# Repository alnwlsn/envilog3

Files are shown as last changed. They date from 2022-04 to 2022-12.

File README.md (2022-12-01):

# envilog3
2022 version of my enviromental logger board - original version documented on [Hackaday.io](https://hackaday.io/project/160740-low-power-environment-monitor-logger) or [my website](https://alnwlsn.com/projectrepository/index.php/Electronic_Time_Capsule).

This is a little board that I packed with batteries, some sensors, a Flash chip, and an RTC. When the RTC wakes up the board on some interval (programmable; minutes to an hour), it reads the sensors and stores the data in the Flash chip. The rest of the time, the board is in a low power sleep state, drawing <10uA. With 4xAA cells of power, the whole thing should run for several years.

I added a bunch of sensor footprints to this version because I had space and wasn't sure which ones I'd be able to get in the 2022 chip shortage. But, the firmware provided is for this configuration:
* BME280 (pressure, temperature, humidity)
* SHT31-DIS (temperature, humidity)
* BH1730FVC (light sensor; visible & IR)
* DS3232M (Real-time clock chip, also contains temperature sensor)
* Battery voltage (using Atmega ADC & voltage divider)
* 16MB of Flash; enough for 512K samples.
  * This is about 1 year of data at a 1 minute interval. Scale as needed - I'm going for 6 minute interval --> 6 years.

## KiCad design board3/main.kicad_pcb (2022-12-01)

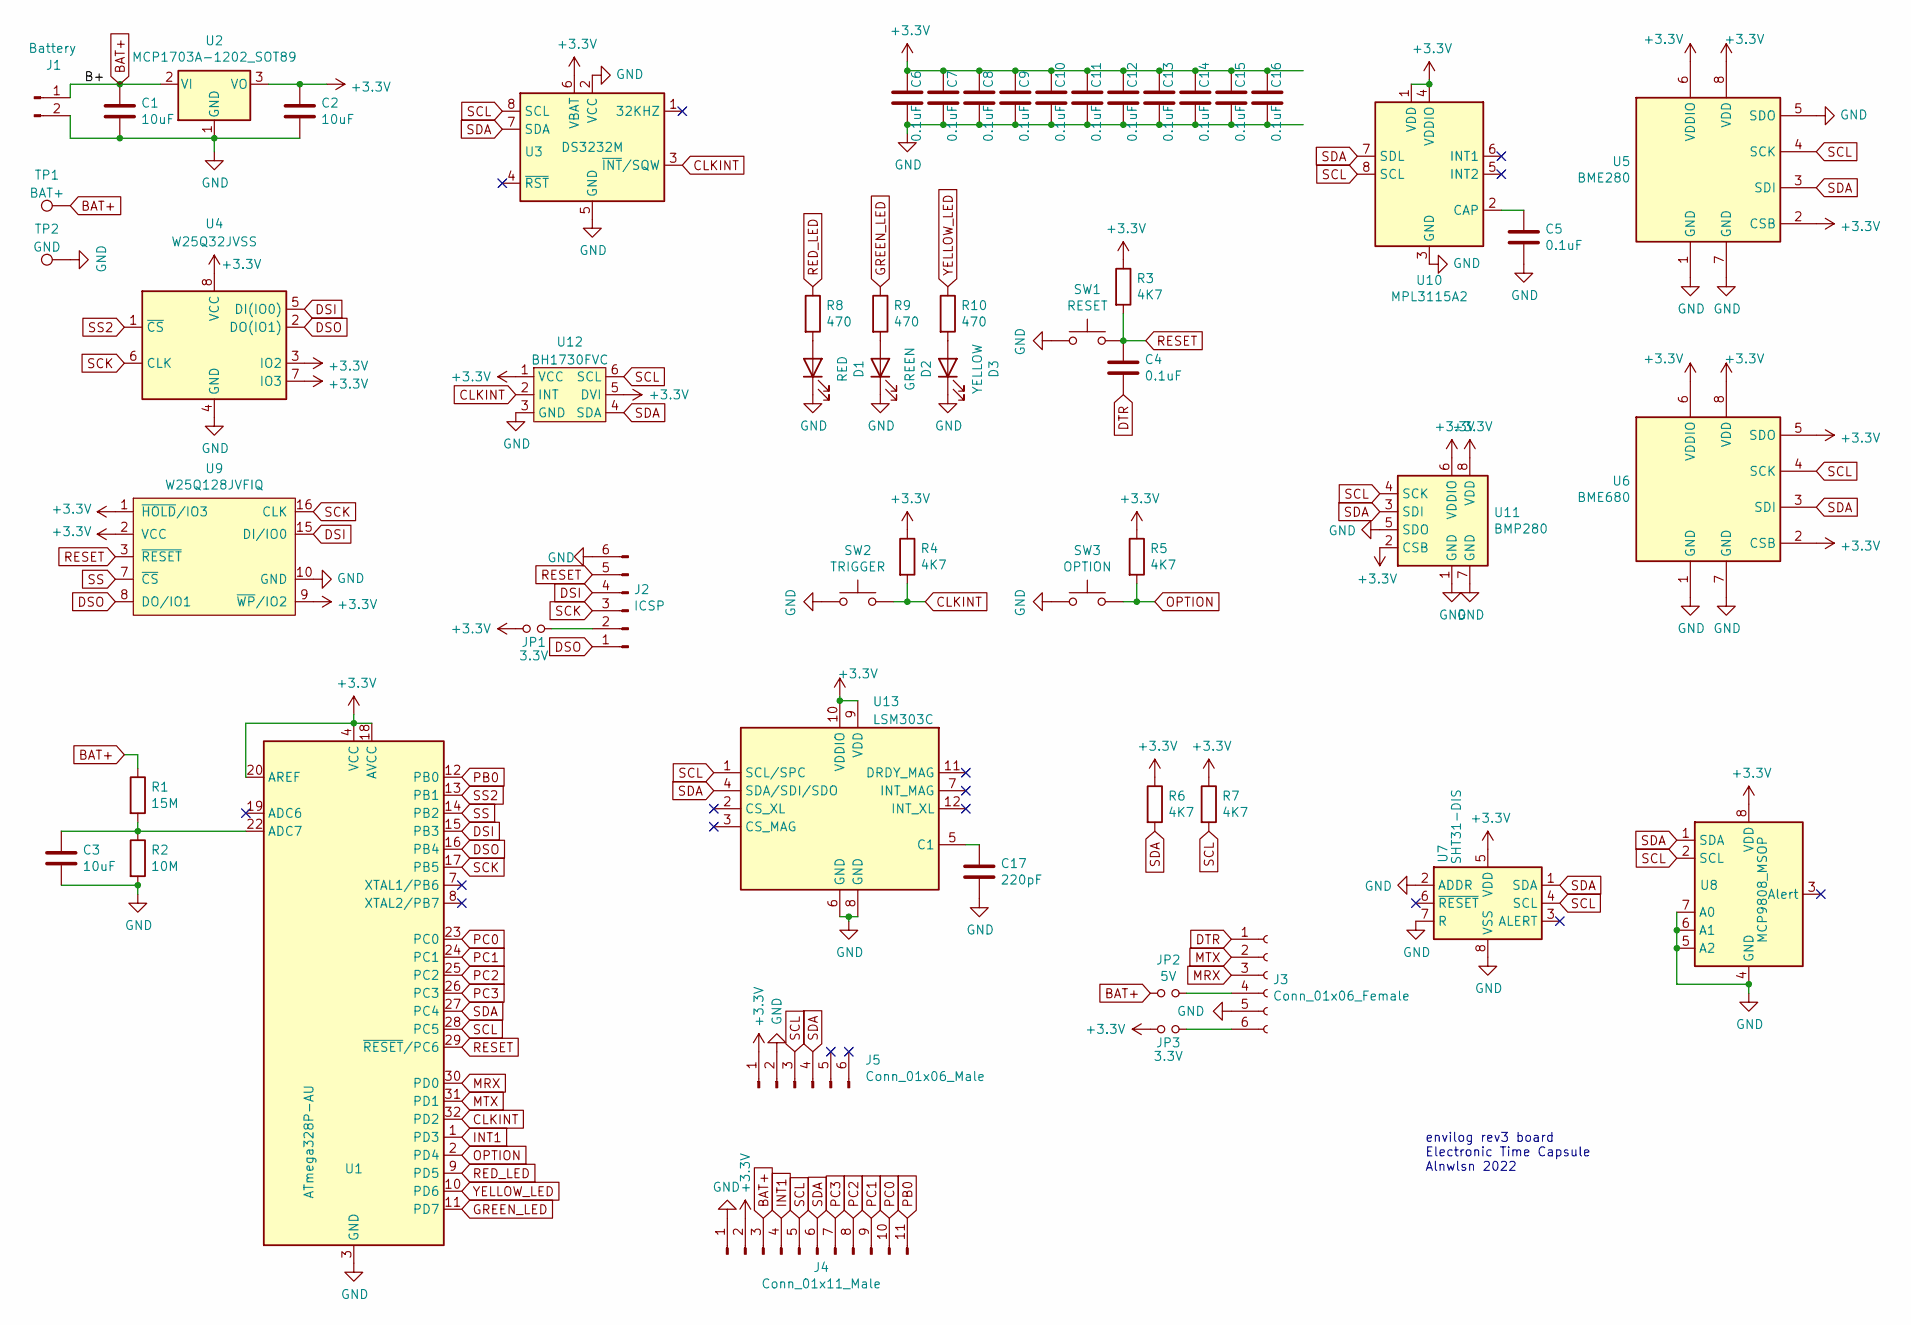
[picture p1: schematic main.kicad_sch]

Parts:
C1, C2, C3: 10uF; C_0805_2012Metric
C4, C5, C6, C7, C8, C9, C10, C11, C12, C13, C14, C15, C16: 0.1uF; C_0805_2012Metric
C17: 220pF; C_0805_2012Metric
D1: RED; LED_0805_2012Metric
D2: GREEN; LED_0805_2012Metric
D3: YELLOW; LED_0805_2012Metric
J1: Battery; PinHeader_1x02_P2.54mm_Vertical
J2: ICSP; PinHeader_2x03_P2.54mm_Vertical
J3: Conn_01x06_Female; PinSocket_1x06_P2.54mm_Vertical
J4: Conn_01x11_Male; PinHeader_1x11_P2.54mm_Vertical
J5: Conn_01x06_Male; PinHeader_1x06_P2.54mm_Vertical
JP1, JP3: 3.3V; SolderJumper-2_P1.3mm_Open_RoundedPad1.0x1.5mm
JP2: 5V; SolderJumper-2_P1.3mm_Open_RoundedPad1.0x1.5mm
R1: 15M; R_0805_2012Metric
R2: 10M; R_0805_2012Metric
R3, R4, R5, R6, R7: 4K7; R_0805_2012Metric
R8, R9, R10: 470; R_0805_2012Metric
SW1: RESET; SW_SPST_SKQG_WithStem
SW2: TRIGGER; SW_SPST_SKQG_WithStem
SW3: OPTION; SW_SPST_SKQG_WithStem
TP1: BAT+; 4mm-bslot
TP2: GND; 4mm-bslot
U1: ATmega328P-AU; TQFP-32_7x7mm_P0.8mm
U2: MCP1703A-1202_SOT89; SOT-89-3
U3: DS3232M; SOIC-8_3.9x4.9mm_P1.27mm
U4: W25Q32JVSS; SOIC-8_5.23x5.23mm_P1.27mm
U5: BME280; Bosch_LGA-8_2.5x2.5mm_P0.65mm_ClockwisePinNumbering
U6: BME680; Bosch_LGA-8_3x3mm_P0.8mm_ClockwisePinNumbering
U7: SHT31-DIS; Sensirion_DFN-8-1EP_2.5x2.5mm_P0.5mm_EP1.1x1.7mm
U8: MCP9808_MSOP; MSOP-8_3x3mm_P0.65mm
U9: W25Q128JVFIQ; SOIC-16W_7.5x10.3mm_P1.27mm
U10: MPL3115A2; NXP_LGA-8_3x5mm_P1.25mm_H1.1mm
U11: BMP280; Bosch_LGA-8_2x2.5mm_P0.65mm_ClockwisePinNumbering
U12: BH1730FVC; WSOF-6
U13: LSM303C; LGA-12_2x2mm_P0.5mm

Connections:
+3V3: C2.1, C6.1, C7.1, C8.1, C9.1, C10.1, C11.1, C12.1, C13.1, C14.1, C15.1, C16.1, J4.2, J5.1, JP1.1, JP3.1, R3.1, R4.1, R5.1, R6.1, R7.1, U1.4 (VCC), U1.6 (VCC), U1.18 (AVCC), U1.20 (AREF), U2.3 (VO), U3.6 (VBAT), U4.3 (IO2), U4.7 (IO3), U4.8 (VCC), U5.2 (CSB), U5.6 (VDDIO), U5.8 (VDD), U6.2 (CSB), U6.5 (SDO), U6.6 (VDDIO), U6.8 (VDD), U7.5 (VDD), U8.8 (VDD), U9.1 (~HOLD/IO3), U9.2 (VCC), U9.9 (~WP/IO2), U10.1 (VDD), U10.4 (VDDIO), U11.2 (CSB), U11.6 (VDDIO), U11.8 (VDD), U12.1 (VCC), U12.5 (DVI), U13.9 (VDD), U13.10 (VDDIO)
BAT+: C1.2, J1.1, J4.3, JP2.1, R1.1, TP1.1, U2.2 (VI)
CLKINT: R4.2, SW2.2, U1.32 (PD2), U3.3 (~INT/SQW), U12.2 (INT)
DSI: J2.4, U1.15 (PB3), U4.5 (DI(IO0)), U9.15 (DI/IO0)
DSO: J2.1, U1.16 (PB4), U4.2 (DO(IO1)), U9.8 (DO/IO1)
DTR: C4.2, J3.1
GND: C1.1, C2.2, C3.2, C5.2, C6.2, C7.2, C8.2, C9.2, C10.2, C11.2, C12.2, C13.2, C14.2, C15.2, C16.2, C17.2, D1.1 (K), D2.1 (K), D3.1 (K), J1.2, J2.6, J3.5, J4.1, J5.2, R2.2, SW1.1, SW2.1, SW3.1, TP2.1, U1.3 (GND), U1.5 (GND), U1.21 (GND), U2.1 (GND), U3.2 (VCC), U3.5 (GND), U4.4 (GND), U5.1 (GND), U5.5 (SDO), U5.7 (GND), U6.1 (GND), U6.7 (GND), U7.2 (ADDR), U7.7 (R), U7.8 (VSS), U7.9 (VSS), U8.4 (GND), U8.5 (A2), U8.6 (A1), U8.7 (A0), U9.10 (GND), U10.3 (GND), U11.1 (GND), U11.5 (SDO), U11.7 (GND), U12.3 (GND), U13.6 (GND), U13.8 (GND)
GREEN_LED: R9.1, U1.11 (PD7)
INT1: J4.4, U1.1 (PD3)
MRX: J3.3, U1.30 (PD0)
MTX: J3.2, U1.31 (PD1)
unnamed: C3.1, R1.2, R2.1, U1.22 (ADC7)
unnamed: C5.1, U10.2 (CAP)
unnamed: C17.1, U13.5 (C1)
unnamed: D1.2 (A), R8.2
unnamed: D2.2 (A), R9.2
unnamed: D3.2 (A), R10.2
unnamed: J2.2, JP1.2
unnamed: J3.4, JP2.2
unnamed: J3.6, JP3.2
OPTION: R5.2, SW3.2, U1.2 (PD4)
PB0: J4.11, U1.12 (PB0)
PC0: J4.10, U1.23 (PC0)
PC1: J4.9, U1.24 (PC1)
PC2: J4.8, U1.25 (PC2)
PC3: J4.7, U1.26 (PC3)
RED_LED: R8.1, U1.9 (PD5)
RESET: C4.1, J2.5, R3.2, SW1.2, U1.29 (~RESET/PC6), U9.3 (~RESET)
SCK: J2.3, U1.17 (PB5), U4.6 (CLK), U9.16 (CLK)
SCL: J4.5, J5.3, R7.2, U1.28 (PC5), U3.8 (SCL), U5.4 (SCK), U6.4 (SCK), U7.4 (SCL), U8.2 (SCL), U10.8 (SCL), U11.4 (SCK), U12.6 (SCL), U13.1 (SCL/SPC)
SDA: J4.6, J5.4, R6.2, U1.27 (PC4), U3.7 (SDA), U5.3 (SDI), U6.3 (SDI), U7.1 (SDA), U8.1 (SDA), U10.7 (SDL), U11.3 (SDI), U12.4 (SDA), U13.4 (SDA/SDI/SDO)
SS: U1.14 (PB2), U9.7 (~CS)
SS2: U1.13 (PB1), U4.1 (~CS)
YELLOW_LED: R10.1, U1.10 (PD6)

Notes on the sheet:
envilog rev3 board Electronic Time Capsule Alnwlsn 2022

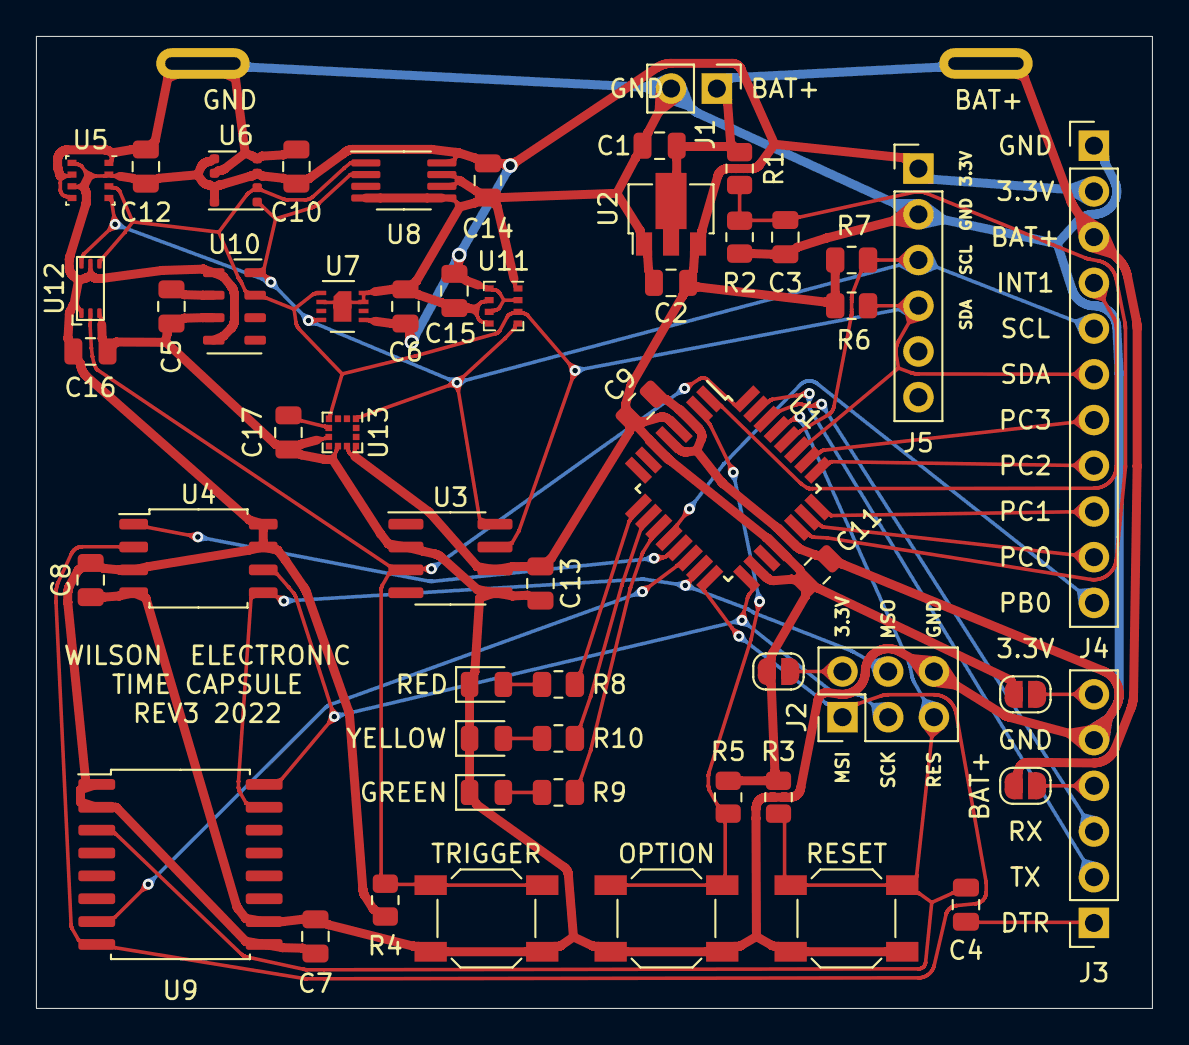
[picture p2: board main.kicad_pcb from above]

Board: 2 copper layers, 62.0 x 54.0 mm, 56 parts (0 on the bottom side), 34 nets.

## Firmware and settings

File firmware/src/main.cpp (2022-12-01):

#include <Arduino.h>
#include <EEPROM.h>
#include <SPI.h>
#include <avr/sleep.h>
#include <avr/wdt.h>

// #include "BH1730.h"
#include "SHT31.h"
#include "SPIMemory/src/SPIMemory.h"
#include "SparkFunBME280.h"
#include "Wire.h"

#define intClk 2
#define int1 1  // unused
#define buttonOption 4
#define ledGreen 7
#define ledYellow 6
#define ledRed 5

struct frame_t {  // structure that stores each frame (32 bytes)
    uint32_t count;

    uint8_t year;
    uint8_t month;
    uint8_t day;
    uint8_t hour;
    uint8_t minute;
    uint8_t second;

    int16_t temperatureBME;
    int16_t temperatureSHT;
    int16_t temperatureRTC;
    int16_t humidityBME;
    int16_t humiditySHT;
    float pressureBME;
    uint16_t lightVis;
    uint16_t lightIr;
    uint16_t batteryADC;
    uint16_t avrTherm;
};
frame_t frame;
void printBin(byte temp) {
    Serial.print(F("0b"));
    for (uint8_t y = 0; y <= 7; y++) {
        if (temp & (0x80)) {
            Serial.print(F("1"));
        } else {
            Serial.print(F("0"));
        }
    }
}
void printHex(byte temp) {
    if (temp < 0x10) {
        Serial.print('0');
    }
    Serial.print(temp, HEX);
}

class DS3231 {  // my own custom lib for control of the DS3231
    uint8_t RTC_ADDR = 0x68;

    uint8_t ztimeSecond;
    uint8_t ztimeMinute;
    uint8_t ztimeHour;
    uint8_t ztimeDay;
    uint8_t ztimeMonth;
    uint8_t ztimeYear;
    uint8_t ztimeWeekday;

    uint8_t za1rmb;  // alarm register bits - set first, then set the time, day, month, etc to get this value into the clock
    uint8_t za2rmb;

   public:
    DS3231() {}

    static uint8_t bcd2bin(uint8_t val) { return val - 6 * (val >> 4); }
    static uint8_t bin2bcd(uint8_t val) { return val + 6 * (val / 10); }
    uint8_t read_register(uint8_t reg) {
        Wire.beginTransmission(RTC_ADDR);
        Wire.write((uint8_t)reg);
        Wire.endTransmission();
        Wire.requestFrom(RTC_ADDR, (uint8_t)1);
        return Wire.read();
    }
    void write_register(uint8_t reg, uint8_t val) {
        Wire.beginTransmission(RTC_ADDR);
        Wire.write((uint8_t)reg);
        Wire.write((uint8_t)val);
        Wire.endTransmission();
    }

    void setTimeSecond(uint8_t temp) { write_register(0x00, bin2bcd(temp)); }
    void setTimeMinute(uint8_t temp) { write_register(0x01, bin2bcd(temp)); }
    void setTimeHour(uint8_t temp) { write_register(0x02, bin2bcd(temp)); }
    void setTimeDay(uint8_t temp) { write_register(0x04, bin2bcd(temp)); }
    void setTimeMonth(uint8_t temp) { write_register(0x05, bin2bcd(temp)); }
    void setTimeYear(int temp) { write_register(0x06, bin2bcd(temp)); }
    void validateClock() {
        uint8_t bstat = read_register(0x0F);
        bstat &= ~0x80;
        write_register(0x0F, bstat);
    }  // Clears OSF
    bool lostPower(void) { return (read_register(0x0f) >> 7); }
    void getTime() {
        Wire.beginTransmission(RTC_ADDR);  // set to location 0 (seconds)
        Wire.write((uint8_t)0);
        Wire.endTransmission();
        Wire.requestFrom(RTC_ADDR, (uint8_t)7);
        ztimeSecond = bcd2bin(Wire.read() & 0x7F);
        ztimeMinute = bcd2bin(Wire.read());
        ztimeHour = bcd2bin(Wire.read());
        Wire.read();
        ztimeDay = bcd2bin(Wire.read());
        ztimeMonth = bcd2bin(Wire.read());
        ztimeYear = bcd2bin(Wire.read());
    }
    uint8_t csecond() { return ztimeSecond; }
    uint8_t cminute() { return ztimeMinute; }
    uint8_t chour() { return ztimeHour; }
    uint8_t cday() { return ztimeDay; }
    uint8_t cmonth() { return ztimeMonth; }
    uint8_t cyear() { return ztimeYear; }
    uint8_t cweekday() { return ztimeWeekday; }

    void setAlarm1RMB(uint8_t temp) { za1rmb = temp; }
    void setAlarm1Second(uint8_t temp) { write_register(0x07, ((1 & (za1rmb >> 0)) << 7) + bin2bcd(temp)); }  // set alarm bcd and bit 0 of alarm 1 register mask bit
    void setAlarm1Minute(uint8_t temp) { write_register(0x08, ((1 & (za1rmb >> 1)) << 7) + bin2bcd(temp)); }
    void setAlarm1Hour(uint8_t temp) { write_register(0x09, ((1 & (za1rmb >> 2)) << 7) + bin2bcd(temp)); }
    void setAlarm1Weekday(uint8_t temp) { write_register(0x0a, (0b01000000) | (((1 & (za1rmb >> 3)) << 7) + bin2bcd(temp))); }
    void setAlarm1Day(uint8_t temp) { write_register(0x0a, (~0b01000000) & (((1 & (za1rmb >> 3)) << 7) + bin2bcd(temp))); }  // if day is set, tell alarm to use it, otherwise, use weekday

    void useAlarm1onINT() {
        uint8_t bcont = read_register(0x0e);
        bcont |= 0b00000001;
        write_register(0x0e, bcont);
    }  // sets A1IE
    void dontUseAlarm1onINT() {
        uint8_t bcont = read_register(0x0e);
        bcont &= ~0b00000001;
        write_register(0x0e, bcont);
    }  // clears A1IE
    void resetAlarm1() {
        uint8_t bstat = read_register(0x0f);
        bstat &= ~0b00000001;
        write_register(0x0f, bstat);
    }  // clears alarm 1 flag
    float getTemp() {
        int8_t temp_msb, temp_lsb;
        Wire.beginTransmission(RTC_ADDR);
        Wire.write(0x11);
        Wire.endTransmission();
        Wire.requestFrom(RTC_ADDR, (uint8_t)2);
        temp_msb = Wire.read();
        temp_lsb = (Wire.read() >> 6) & 0x03;
        Wire.endTransmission();
        if (temp_msb & 0b10000000) {  // check if negative number
            temp_msb ^= 0b11111111;
            temp_msb += 0x1;
            return (-1.0 * ((float)temp_msb) + ((float)temp_lsb * 0.25));
        } else {
            return ((float)temp_msb + ((float)temp_lsb * 0.25));
        }
    }
    void printRegs() {
        Serial.print(F("DS3231 registers:\r\n"));
        Serial.print(F("ADR DAT(BIN)\r\n"));
        for (byte j = 0; j <= 0x12; j++) {
            printHex(j);
            Serial.print(' ');
            printBin(read_register(j));
            Serial.println();
        }
        Serial.print(F("\r\n"));
    }
    void printTime() {
        getTime();
        Serial.print(F("Current time: "));
        if (cyear() < 10) {
            Serial.print('0');
        }
        Serial.print(cyear());
        Serial.print('/');
        if (cmonth() < 10) {
            Serial.print('0');
        }
        Serial.print(cmonth());
        Serial.print('/');
        if (cday() < 10) {
            Serial.print('0');
        }
        Serial.print(cday());
        Serial.print(' ');
        if (chour() < 10) {
            Serial.print('0');
        }
        Serial.print(chour());
        Serial.print(':');
        if (cminute() < 10) {
            Serial.print('0');
        }
        Serial.print(cminute());
        Serial.print(':');
        if (csecond() < 10) {
            Serial.print('0');
        }
        Serial.println(csecond());
    }
};

DS3231 rtc;
// BH1730 lightSensor;
#define SHT31_ADDRESS 0x44
SHT31 sht;
BME280 bme;
SPIFlash flash;

void msg() {  // reads EEPROM stored message
    Serial.print(F("*******\r\n"));
    char rxb;
    int eindex = 0;
    while (1) {
        rxb = EEPROM.read(eindex);
        if (rxb == 13) {
            Serial.write(10);
        }
        if (rxb == '\\') {
            break;
        }
        Serial.write(rxb);
        if (eindex >= 1023) {
            break;
        }
        eindex++;
    }
    Serial.print(F("\r\n*******\r\n"));
}

void wakeISR() {  // just wakes the chip and disables interrupts until next time
    sleep_disable();
    detachInterrupt(0);
    detachInterrupt(1);
}
void printFrameHeader() {
    Serial.print(F("Count\tYear\tMonth\tDay\tHour\tMinute\tSecond\tAVR Temp (ADC)\tDS3232 Temp (C)\tBME Temp (C)\tSHT Temp (C)\tBME RH (%)\tSHT RH (%)\tBME Pressure (pa)\tLight Vis (raw)\tLight IR (raw)\tBatt (ADC)\r\n"));
}
void printFrame(frame_t current) {  // prints one line of frame data
    Serial.print(current.count);
    Serial.print('\t');
    Serial.print(current.year);
    Serial.print('\t');
    Serial.print(current.month);
    Serial.print('\t');
    Serial.print(current.day);
    Serial.print('\t');
    Serial.print(current.hour);
    Serial.print('\t');
    Serial.print(current.minute);
    Serial.print('\t');
    Serial.print(current.second);
    Serial.print('\t');
    Serial.print(current.avrTherm);
    Serial.print('\t');
    Serial.print(current.temperatureRTC / 100.0);
    Serial.print('\t');
    Serial.print(current.temperatureBME / 100.0);
    Serial.print('\t');
    Serial.print(current.temperatureSHT / 100.0);
    Serial.print('\t');
    Serial.print(current.humidityBME / 100.0);
    Serial.print('\t');
    Serial.print(current.humiditySHT / 100.0);
    Serial.print('\t');
    Serial.print(current.pressureBME);
    Serial.print('\t');
    Serial.print(current.lightVis);
    Serial.print('\t');
    Serial.print(current.lightIr);
    Serial.print('\t');
    Serial.print(current.batteryADC);
    Serial.println();
}
void printProjectHeader() {
    Serial.println(F("TIME CAPSULE LONG DURATION ENVIROMENTAL LOGGER - v10 (2022-04-24) - Compiled 2022-11-30 - Alan J. Wilson"));
}
frame_t wakeupMeasure() {  // wake up from sleep, initialize and do the measurements
    Wire.begin();
    SPI.begin();
    ADCSRA = 134;
    ADMUX = (_BV(REFS1) | _BV(REFS0) | _BV(MUX3));  // for AVR therm
    ADCSRA |= _BV(ADEN);
    pinMode(ledGreen, OUTPUT);
    pinMode(ledRed, OUTPUT);
    pinMode(ledYellow, OUTPUT);
    rtc.resetAlarm1();
    flash.powerUp();

    bme.settings.commInterface = I2C_MODE;
    bme.settings.I2CAddress = 0x76;
    bme.settings.runMode = 3;  // 3 for normal mode (ON), 0 for sleep mode (OFF)
    bme.settings.tStandby = 0;
    bme.settings.filter = 0;
    bme.settings.tempOverSample = 8;
    bme.settings.pressOverSample = 8;
    bme.settings.humidOverSample = 8;
    bme.begin();

    sht.begin();
    sht.reset();
    sht.read();

    ADCSRA |= _BV(ADSC);  // for AVR therm

    // lightSensor.begin();
    // lightSensor.reset();
    // lightSensor.setGain(GAIN_X1);
    // lightSensor.measure();

    while (bit_is_set(ADCSRA, ADSC))
        ;  // avr therm

    // collect sensor info
    frame_t current;
    current.avrTherm = ADCW;  // avr therm
    current.temperatureRTC = rtc.getTemp() * 100;
    current.temperatureSHT = sht.getTemperature() * 100;
    current.humiditySHT = sht.getHumidity() * 100;
    current.temperatureBME = bme.readTempC() * 100;
    current.humidityBME = bme.readFloatHumidity() * 100;
    current.pressureBME = bme.readFloatPressure();
    current.lightVis = 255; //lightSensor.readVis();
    current.lightIr = 255; //lightSensor.readIr();
    current.batteryADC = analogRead(A7);
    return current;
}
uint32_t findIndex() {  // finds next blank area in flash for next index
    uint32_t index = 0;
    while (1) {
        if (!flash.readAnything(index * sizeof(frame), frame)) {
            Serial.println(F("Read failed!"));
            break;
        }
        if (frame.count == 4294967295) {
            break;
        }
        index++;
    }
    return index;
}
bool saveData(uint32_t index, frame_t frame) {
    // Write to the flash chip. The retries are likely unnessacary, but I added them anyways.
    byte retry = 10;
    while (retry > 0) {
        retry--;
        if (flash.writeAnything(index * sizeof(frame), frame)) {
            return true;
        }
        delay(50);
    }
    return false;
}
void frameTimestamp(struct frame_t* current) {  // timestamps frame with current time
    rtc.getTime();
    current->year = rtc.cyear();
    current->month = rtc.cmonth();
    current->day = rtc.cday();
    current->hour = rtc.chour();
    current->minute = rtc.cminute();
    current->second = rtc.csecond();
}
uint32_t frameIndex = 0;
uint32_t frameCount = 0;
uint8_t nextMinuteTrigger = 0;

//***************************Wilson Command Console******************************
#include <string.h>
#define serbuflen 50             // total length of single line of input
#define paramMax 10              // number of parameters that will be split
char serbuf[serbuflen + 1];      // buffer for storing serial input text
unsigned short serbufIndex = 0;  // index pointer for serbuf
char* param[paramMax];           // stores pointers to parameters
short params;                    // stores number of parameters got
void consoleProcess() {          // splits out the parameters
    char* tmp;
    params = -1;
    tmp = strtok(serbuf, " ");
    if (tmp != NULL) {
        params = 0;
        param[params] = tmp;
    } else {
        return;
    }
    while (tmp != NULL) {
        tmp = strtok(NULL, " ");
        if (tmp != NULL) {
            params++;
            if (params >= paramMax) {
                params = paramMax - 1;
            }
            param[params] = tmp;
        }
    }
}
void consoleOperate() {                           // act on the parameters we got
    if (0 == strcmp_P(param[0], PSTR("time"))) {  // sets the RTC
        Serial.print(F("\r\n"));
        if (params <= 1) {
            rtc.printTime();
        } else {
            rtc.setTimeYear(strtol(param[1], NULL, 10));
            rtc.setTimeMonth(strtol(param[2], NULL, 10));
            rtc.setTimeDay(strtol(param[3], NULL, 10));
            rtc.setTimeHour(strtol(param[4], NULL, 10));
            rtc.setTimeMinute(strtol(param[5], NULL, 10));
            rtc.setTimeSecond(strtol(param[6], NULL, 10));
            rtc.resetAlarm1();
            rtc.validateClock();
            rtc.printTime();
        }
        // Serial.print(F("\r\n1st parameter (int/prn in Hex)"));
        //   Serial.println(strtol(param[1], NULL, 16), HEX);
        // Serial.print(F("2nd parameter (int/prn in Dec)"));
        //   Serial.println(strtol(param[2], NULL, 10));
        // Serial.print(F("3rd parameter (int/prn in Bin)"));
        //   Serial.println(strtol(param[3], NULL, 2), BIN);
    }
    if (0 == strcmp_P(param[0], PSTR("speed"))) {
        if (params >= 1) {
            Serial.begin(strtol(param[1], NULL, 10));
        }
    }
    if (0 == strcmp_P(param[0], PSTR("dump"))) {
        unsigned long start = 0;
        if (params >= 1) {
            start = strtol(param[1], NULL, 10);
        }
        while (Serial.available()) {
            Serial.read();
        }  // empty serial register
        Serial.println();
        printFrameHeader();
        for (unsigned long t = start; t < (flash.getCapacity() / (int)sizeof(frame)); t++) {
            frame_t dumpFrame;
            flash.readAnything(t * sizeof(frame), dumpFrame);
            printFrame(dumpFrame);
            if (digitalRead(buttonOption) == 0) {
                return;
            }
            if (Serial.available()) {
                return;
            }
        }
    }
    if (0 == strcmp_P(param[0], PSTR("erase"))) {
        Serial.print(F("\r\n"));
        flash.eraseChip();
        frameIndex = 0;
        frameCount = 0;
    }
    if (0 == strcmp_P(param[0], PSTR("sensors"))) {
        Serial.print(F("\r\n"));
        frame_t current = wakeupMeasure();
        frameTimestamp(&current);
        current.count = frameCount;
        printFrame(current);
    }
    if (0 == strcmp_P(param[0], PSTR("reset"))) {
        Serial.print(F("\r\n"));
        wdt_enable(WDTO_15MS);
        for (;;) {
        }
    }
    if (0 == strcmp_P(param[0], PSTR("new"))) {
        Serial.print(F("\r\n"));
        char rxb = 0;
        int eindex = 0;
        while (1) {
            if (Serial.available()) {
                rxb = Serial.read();
                if (rxb == 13) {
                    Serial.write(10);
                }
                EEPROM.write(eindex, rxb);
                if (rxb == '\\') {
                    break;
                }
                Serial.write(rxb);
                if (eindex >= 1023) {
                    break;
                }
                eindex++;
            }
        }
    }
    if (0 == strcmp_P(param[0], PSTR("msg"))) {
        Serial.print(F("\r\n"));
        msg();
    }
    if (0 == strcmp_P(param[0], PSTR("?"))) {
        Serial.print(F("\r\ntime [YY MM DD HH MM SS] - show / set current RTC time\r\nspeed [baudrate]         - set serial console baudrate\r\ndump                     - dump saved Flash data\r\nerase                    - erase flash chip\r\nsensors                  - read all sensors and print data\r\nreset                    - reset AVR\r\nnew                      - write new EEPROM message\r\nmsg                      - display current EEPROM message\r\n"));
    }
}
void consoleRun() {
    while (Serial.available()) {
        serbuf[serbufIndex] = Serial.read();
        if (serbuf[serbufIndex] == 13) {
            serbuf[serbufIndex] = 0;
            serbufIndex = 0;
            consoleProcess();  // split the parameters
            if (params >= 0) {
                consoleOperate();  // operate the console given parameters
                                   // for(int y=0; y<=params; y++){printf("%d - %s\r\n",y,param[y]);}
            }
            Serial.print(F("\r\n>"));
        } else if (serbuf[serbufIndex] == 8 || serbuf[serbufIndex] == 127) {
            if (serbufIndex != 0) {
                serbufIndex--;
                Serial.write(8);
                Serial.write(32);
                Serial.write(8);
            }
        } else {
            Serial.write(serbuf[serbufIndex]);
            serbufIndex++;
            if (serbufIndex >= serbuflen) {
                serbufIndex = serbuflen;
            }
        }
    }
}

void setup() {
    MCUSR = 0;
    wdt_disable();
    Serial.begin(115200);
    flash.begin(MB(16));
    wakeupMeasure();  // init hardware
    pinMode(buttonOption, INPUT);
    if (digitalRead(buttonOption) == 0) {
        pinMode(ledYellow, OUTPUT);
        digitalWrite(ledYellow, HIGH);
        Serial.begin(9600);
        printProjectHeader();
        Serial.print(F("Welcome to the Command Console! (? for command list)\r\n>"));
        while (1) {
            consoleRun();
        }
    }
    printProjectHeader();
    Serial.print(F("Hold Option and press Reset for Command Console\r\n"));

    Serial.print(F("Flash capacity: "));
    Serial.print(flash.getCapacity());
    Serial.print(F(" bytes, "));
    Serial.print((flash.getCapacity() / (int)sizeof(frame)));
    Serial.print(F(" frames (frame size: "));
    Serial.print((int)sizeof(frame));
    Serial.print(F(")\r\nNext frame index: "));
    frameIndex = findIndex();
    Serial.println(frameIndex);
}
void loop() {
    // wakeup here initize stuff
    frame_t current = wakeupMeasure();
    frameTimestamp(&current);
    current.count = frameCount;

    Serial.begin(115200);
    Serial.println();

    if (frameIndex <= (flash.getCapacity() / (int)sizeof(frame))) {
        bool sd = saveData(frameIndex, current);
        if (sd) {
            Serial.print(F("Saved!\r\n"));
            digitalWrite(ledGreen, HIGH);
            frameIndex++;
            frameCount++;
        } else {
            Serial.print(F("Save FAILED!\r\n"));
            digitalWrite(ledRed, HIGH);
        }
    } else {
        Serial.print(F("flash FULL!\r\n"));
        digitalWrite(ledRed, HIGH);
    }

    rtc.printTime();
    printFrame(current);

    //Set RTC alarm for the next trigger
    nextMinuteTrigger = rtc.cminute() + 6;
    if(nextMinuteTrigger >= 60){
        nextMinuteTrigger = 0;
    }
    //ALARM 1 REGISTER MASK BITS - 0b1110 trips timer when seconds match. 0b1100 trips timer when minutes and seconds match.
    rtc.setAlarm1RMB(0b1100);
    rtc.setAlarm1Day(27);
    rtc.setAlarm1Hour(11);
    rtc.setAlarm1Minute(nextMinuteTrigger);
    rtc.setAlarm1Second(0);
    rtc.useAlarm1onINT();
    rtc.resetAlarm1();

    // sleep here
    bme.setMode(0);
    sht.reset();
    // lightSensor.reset();
    flash.powerDown();
    digitalWrite(ledRed, LOW);
    digitalWrite(ledGreen, LOW);
    digitalWrite(ledYellow, LOW);
    pinMode(buttonOption, INPUT);
    pinMode(ledRed, INPUT);
    pinMode(ledGreen, INPUT);
    pinMode(ledYellow, INPUT);
    Serial.end();
    Wire.end();
    SPI.end();
    pinMode(0, INPUT);
    pinMode(1, INPUT);
    delay(1);
    ADCSRA = 0;  // Shutdown procedure from the Nick Gammon fourms
    set_sleep_mode(SLEEP_MODE_PWR_DOWN);
    sleep_enable();
    noInterrupts();                        // stop any interrups before sleeping
    attachInterrupt(0, wakeISR, FALLING);  // goto 'wake' on interrupt (using clock alarm)
    EIFR = bit(INTF0);                     // clear flag for interrupt 0
    interrupts();                          // start interrups and
    sleep_cpu();                           // then immediately sleep
}

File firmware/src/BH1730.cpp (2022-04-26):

/*

  Simple library to use a BH1730FVI Digital Light Sensor.

  Uses I2C communication.

  Written by Janco Kock, Jan 2021.

*/

#include "BH1730.h"

/**
 * Constructor
 *
 */
BH1730::BH1730() {}

/**
 * Configure sensor
 */
bool BH1730::begin() {
    Wire.begin();

    // Verify if there is a BH1730 on this address
    if ((read8(BH1730_REG_PART_ID) >> 4) != BH1730_PART_NUMBER) {
#if BH1730_DEBUG == 1
        Serial.println("BH1730 not found");
#endif
        return false;
    };

    // Reset
    write8(BH1730_CMD_SPECIAL | BH1730_CMD_SPECIAL_SOFT_RESET, (1 << 7));

    // Check if gain is set before begin
    if (gain != GAIN_X1) {
        setGain(gain);
    }

    return true;
}

void BH1730::reset() {
    // be sure to have called Wire.begin(); first
    // reset
    write8(BH1730_CMD_SPECIAL | BH1730_CMD_SPECIAL_SOFT_RESET, (1 << 7));
}

/**
 *  Set gain of the internal ADC
 *
 */
void BH1730::setGain(BH1730_GAIN gain) {
    if (gain == GAIN_X1) {
        write8(BH1730_REG_GAIN, BH1730_GAIN_X1_MODE);
    } else if (gain == GAIN_X2) {
        write8(BH1730_REG_GAIN, BH1730_GAIN_X2_MODE);
    } else if (gain == GAIN_X64) {
        write8(BH1730_REG_GAIN, BH1730_GAIN_X64_MODE);
    } else if (gain == GAIN_X128) {
        write8(BH1730_REG_GAIN, BH1730_GAIN_X128_MODE);
    } else {
#if BH1730_DEBUG == 1
        Serial.println("Gain invalid");
#endif
        return;
    }
    BH1730::gain = gain;
}

/**
 * Read lux level from sensor.
 * Returns -1 if read is timed out
 *
 */

bool BH1730::measure() {  // just do measurement, but don't calculate the lux
    write8(BH1730_REG_CONTROL, BH1730_REG_CONTROL_POWER | BH1730_REG_CONTROL_ADC_EN | BH1730_REG_CONTROL_ONE_TIME);

    // Wait for ADC data is valid
    uint8_t ret = 0;

    while (((read8(BH1730_REG_CONTROL) & BH1730_REG_CONTROL_ADC_VALID) == 0) && ++ret < BH1730_RET_TIMEOUT) {
        delay(10);
    }

    if (ret == BH1730_RET_TIMEOUT) {
#if BH1730_DEBUG == 1
        Serial.println("Read timed out");
#endif
        return 0;
    }
    return 1;
}
uint16_t BH1730::readVis() {
    return read16(BH1730_REG_DATA0_LOW);
}
uint16_t BH1730::readIr() {
    return read16(BH1730_REG_DATA1_LOW);
}

float BH1730::readLux() {
    // Start one time measurement
    write8(BH1730_REG_CONTROL, BH1730_REG_CONTROL_POWER | BH1730_REG_CONTROL_ADC_EN | BH1730_REG_CONTROL_ONE_TIME);

    // Wait for ADC data is valid
    uint8_t ret = 0;

    while (((read8(BH1730_REG_CONTROL) & BH1730_REG_CONTROL_ADC_VALID) == 0) && ++ret < BH1730_RET_TIMEOUT) {
        delay(10);
    }

    if (ret == BH1730_RET_TIMEOUT) {
#if BH1730_DEBUG == 1
        Serial.println("Read timed out");
#endif
        return -1;
    }

    // Read real light and IR light from registers
    float data0 = (float)read16(BH1730_REG_DATA0_LOW);
    float data1 = (float)read16(BH1730_REG_DATA1_LOW);

    // Calculate lux based on formula in datasheet.
    if (data0 == 0)
        return 0;

    float lx = 0;
    float div = data1 / data0;

    if (div < 0.26) {
        lx = ((1.29 * data0) - (2.733 * data1)) / gain * 102.6 / BH1730_ITIME_MS;
    } else if (div < 0.55) {
        lx = ((0.795 * data0) - (0.859 * data1)) / gain * 102.6 / BH1730_ITIME_MS;
    } else if (div < 1.09) {
        lx = ((0.51 * data0) - (0.345 * data1)) / gain * 102.6 / BH1730_ITIME_MS;
    } else if (div < 2.13) {
        lx = ((0.276 * data0) - (0.13 * data1)) / gain * 102.6 / BH1730_ITIME_MS;
    }

    return lx;
}

uint8_t BH1730::read8(uint8_t a) {
    uint8_t ret;

    Wire.beginTransmission(BH1730_ADDR);
    Wire.write(a | BH1730_CMD);  // Send register to read from with CMD field
    Wire.endTransmission();

    Wire.beginTransmission(BH1730_ADDR);
    Wire.requestFrom(BH1730_ADDR, 1);  // Wait for 1 byte
    ret = Wire.read();
    Wire.endTransmission();

    return ret;
}

uint16_t BH1730::read16(uint8_t a) {
    uint16_t ret;

    Wire.beginTransmission(BH1730_ADDR);
    Wire.write(a | BH1730_CMD);  // Send register to read from with CMD field

    Wire.endTransmission();

    Wire.beginTransmission(BH1730_ADDR);
    Wire.requestFrom(BH1730_ADDR, 2);  // Wait for 2 bytes
    ret = Wire.read();                 // receive LOW DATA first
    ret |= (Wire.read() << 8);         // receive HIGH DATA and shift to the left
    Wire.endTransmission();

    return ret;
}

void BH1730::write8(uint8_t a, uint8_t d) {
    Wire.beginTransmission(BH1730_ADDR);
    Wire.write(a | BH1730_CMD);  // Send register to write with CMD field
    Wire.write(d);               // Write data
    Wire.endTransmission();
}

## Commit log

2022-04-26 envilog3 - init - board & firmware
    [main.kicad_pcb, main.kicad_sch]
2022-12-01 wc xlvi
    [main.kicad_pcb, main.kicad_sch]
